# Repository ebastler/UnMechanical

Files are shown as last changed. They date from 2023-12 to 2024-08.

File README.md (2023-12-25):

# UnMechanical
 Unmechanical is an attempt to create a capacitive touch keyboard, replacing switches with touchpads.

 The operating principle is pretty much unchanged from the EC boards by [cipulot](https://github.com/Cipulot). Basically, the columns are strobed by the MCU, and the capacitive touchpad forms a capacitive voltage divider together with a 220pF resistor on the PCB. The voltage over the capacitor is measured to determine the capacity of the touchpad, which strongly changes if the pad is touched.

 In order to be able to scan multiple rows, the board uses an analog mux chip that switches from row to row. The input signal is amplified by an OPAMP, since QMK does not offer support for the STM32G431 built-in OPAMPs yet.

## Sweepish
So far, this repository contains a single board, "Sweepish", which consists of a Sweep 3x5 alpha cluster, and a modified 3 key thumb cluster. 

### Features:
* 36 capacitive touch-keys (Layout similar to Sweep)
* Magnetic split connect, allowing for unibody-use
* USB-C PD peripheral of the STM32G431 chip connected to USB-C port
* Circuitry and hole in PCB to mount a Switch Joycon haptic actuator and use it for typing feedback

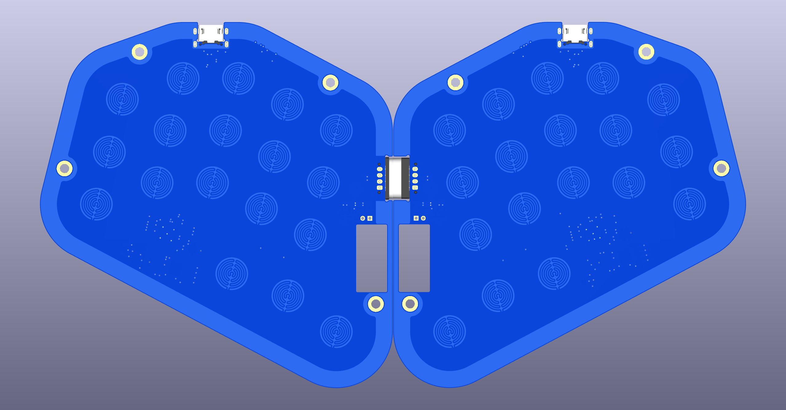
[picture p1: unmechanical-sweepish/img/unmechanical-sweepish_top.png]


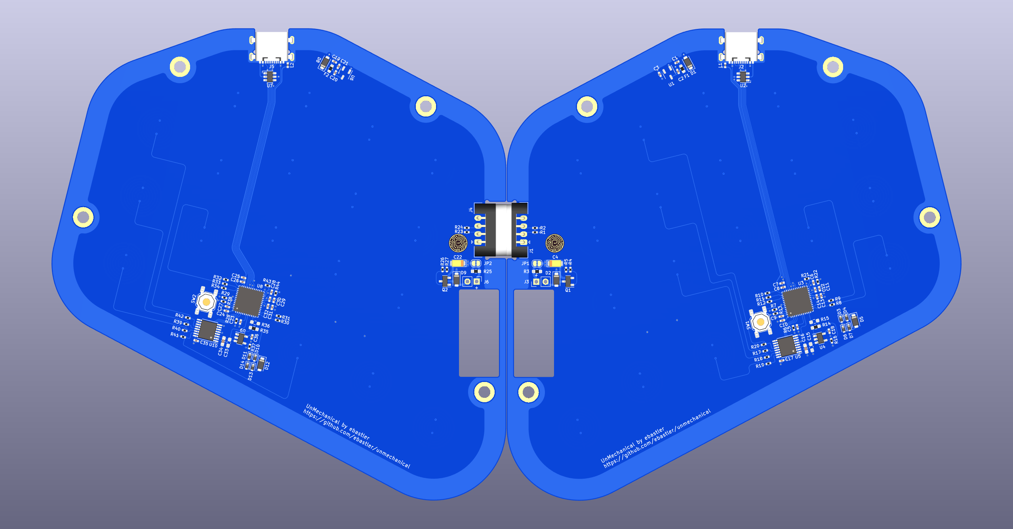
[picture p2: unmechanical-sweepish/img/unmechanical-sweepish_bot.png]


The board is designed to be used as a unibody, held together by HytePro M411P magnetic pogo connectors, but can also be made into a "proper" split board by using a magnetic cable assembly instead.

Firmware support, as well as some optimizations to make the board nicer to use, are still being worked on (so far it can only work as a single half, split EC keyscan does not work yet). The repo is only published as a proof-of-concept - more or less what the entire board design was for, in the first place. 

This keyboard also uses the USB-C PD peripheral of the STM32G431 since I wanted to make a test-board to experiment using it.

### Pictures
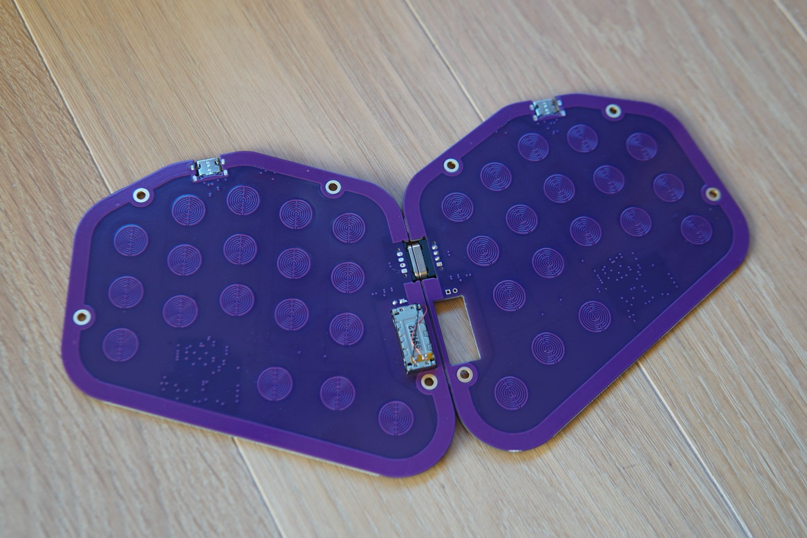
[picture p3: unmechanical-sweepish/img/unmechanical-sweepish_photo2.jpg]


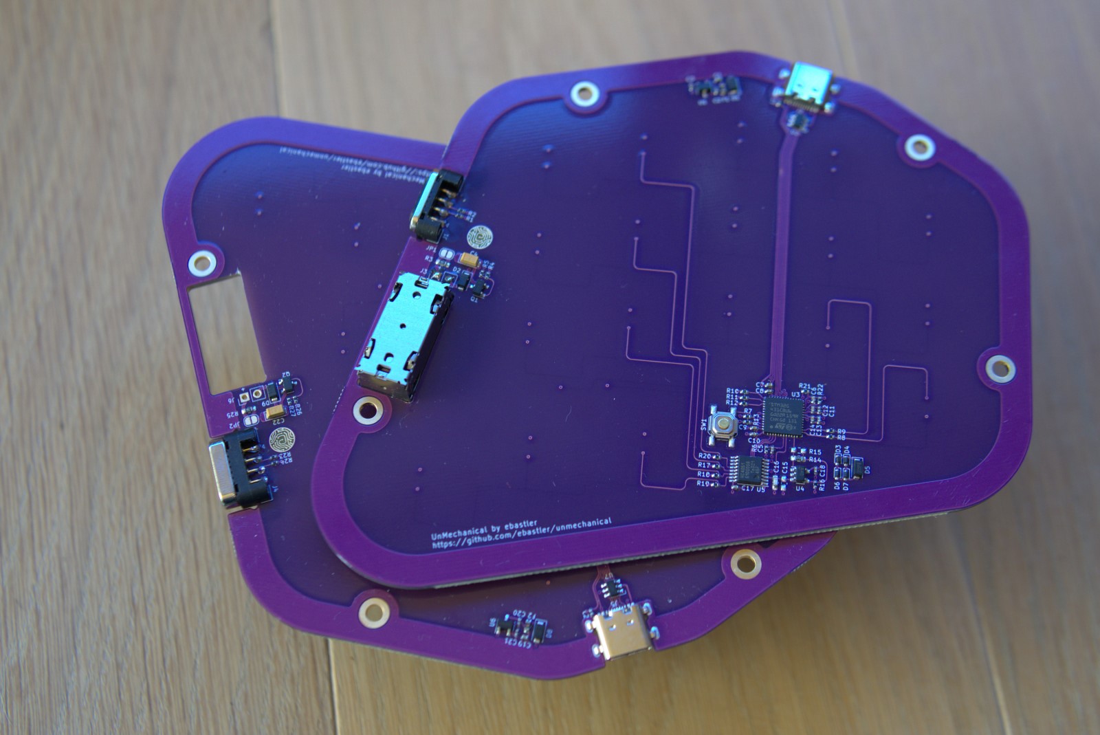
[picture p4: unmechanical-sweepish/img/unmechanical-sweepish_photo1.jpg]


A short video showing the board in action can be found on my youtube channel: https://youtu.be/7uHqJic0PQ8

## Thanks
* [cipulot](https://github.com/Cipulot) for his EC boards, EC QMK keyscan firmwares and help in developing this PCB
* [PCBWay](https://www.pcbway.com/) for the gorgeous sponsored PCBs - couldn't have done it without you!

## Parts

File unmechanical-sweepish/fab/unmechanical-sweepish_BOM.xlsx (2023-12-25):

Item | Reference(s) | Qty | Manufacturer | Manufacturer Part # | Value | Description | Footprint | Type | Notes
1 | C1, C7, C19, C25 | 4 |  |  | 4u7 | 4.7 uF ceramic capacitor, X5R or X7R, 10V, ± 20% or lower | C_0402 | SMD | Manufacturer does not matter
2 | C2, C3, C11, C13, C20, C21, C29, C31 | 8 |  |  | 1u | 1 uF ceramic capacitor, X5R or X7R, 10V, ± 20% or lower | C_0402 | SMD | Manufacturer does not matter
3 | C4, C22 | 2 |  |  | 10u | 10 uF tantalum capacitor, 16V or higher, ± 20% or lower | CP_3216-10_Kemet-A | SMD | Manufacturer does not matter
4 | C5, C6, C8, C9, C10, C14, C17, C18, C23, C24, C26, C27, C28, C32, C35, C36 | 16 |  |  | 100n | 100 nF ceramic capacitor, X5R or X7R, 10V or higher, ± 20% or lower | C_0402 | SMD | Manufacturer does not matter
5 | C12, C30 | 2 |  |  | 10n | 10 nF ceramic capacitor, X5R or X7R, 10V or higher, ± 20% or lower | C_0402 | SMD | Manufacturer does not matter
6 | C15, C33 | 2 |  | DNP | DNP |  | C_0603 | SMD | Do not populate
7 | C16, C34 | 2 |  |  | 220p | 220 pF ceramic capacitor, C0G, 10V or higher, ± 5% | C_0603 | SMD | Manufacturer does not matter
8 | D1, D2, D8, D9 | 4 |  | DS14W |  | 40 V 1 A Schottky diode | D_SOD-123F | SMD | Manufacturer does not matter
9 | D3, D4, D6, D7, D10, D11, D13, D14 | 8 |  | 1N4148WT |  |  | D_SOD-523 | SMD | Manufacturer does not matter
10 | D5, D12 | 2 |  | SMF3.3 |  | 3.3 V TVS diode | D_SOD-123F | SMD | Manufacturer does not matter
11 | F1, F2 | 2 | BHFUSE | BSMD0603-050-6V | 500 mA | 500 mA 6 V resettable polyfuse | Fuse_0603 | SMD | Manufacturer does not matter, other parts of similar specs can be used as replacement
12 | J1 | 1 | HytePro | HTP-CON-M411P-F |  | Spring-loaded magnetic connector | CON_HytePro_M411P_Plug | THT | J1 and J4 are sold as a pair: https://www.hyte.pro/product/m411p.html. Please make sure to not swap them – both should sit flush with PCB edge.
13 | J2, J5 | 2 | HRO Koreaparts | TYPE-C-31-M-14 |  | USB-C receptacle | USB_C_Receptacle_HRO_TYPE-C-31-M-14 | SMD/THT
14 | J4 | 1 | HytePro | HTP-CON-M411P-M |  | Spring-loaded magnetic connector | CON_HytePro_M411P_Receptacle | THT | J1 and J4 are sold as a pair: https://www.hyte.pro/product/m411p.html. Please make sure to not swap them – both should sit flush with PCB edge.
15 | L1, L2 | 2 | MuRata | BLM15PX121SN1D |  | Ferrite bead 2A 55 mOhm 120Ohm @ 100MHz | L_0402 | SMD
16 | Q1, Q2 | 2 | Alpha & Omega Semiconductor | AO3400A |  | 30 V 5.7 A n-ch MOSFET | SOT-23-3 | SMD
17 | R1, R2, R4, R8, R9, R10, R11, R12, R23, R24, R26, R30, R31, R32, R33, R34 | 16 |  |  | 100R | 100 Ohm 1/16W SMD resistor, ± 1% | R_0402 | SMD | Manufacturer does not matter
18 | R3, R25 | 2 |  |  | 4R7 | 4.7 Ohm 1/16W SMD resistor, ± 1% | R_0603 | SMD | Manufacturer does not matter
19 | R5, R6, R7, R13, R27, R28, R29, R38 | 8 |  |  | 10k | 10 kOhm 1/16W SMD resistor, ± 1% | R_0402 | SMD | Manufacturer does not matter
20 | R14, R35 | 2 |  |  | 100k | 100 kOhm 1/16W SMD resistor, ± 1% | R_0603 | SMD | Manufacturer does not matter
21 | R15, R36 | 2 |  | DNP | DNP |  | R_0603 | SMD | Do not populate
22 | R16, R37 | 2 |  |  | 1k | 1 kOhm 1/16W SMD resistor, ± 1% | R_0402 | SMD | Manufacturer does not matter
23 | R17, R18, R19, R20, R39, R40, R41, R42 | 8 |  |  | 100k | 100 kOhm 1/16W SMD resistor, ± 1% | R_0402 | SMD | Manufacturer does not matter
24 | R21, R22, R43, R44 | 4 |  |  | 4k7 | 4.7 kOhm 1/16W SMD resistor, ± 1% | R_0402 | SMD | Manufacturer does not matter
25 | SW1, SW2 | 2 | Alps Alpine | SKQGAKE010 |  | Alps SMD push button | SW_SPST_SKQG | SMD | All SKQGA*E010 models are acceptable as substitutes
26 | U1, U6 | 2 | Torex Semiconductor | XC6206P332MR |  | 3.3V low-dropout voltage regulator IC | SOT-23-3 | SMD
27 | U2, U7 | 2 |  | SRV05-4 |  | 4 channel ESD protection device | SOT-23-6 | SMD | Manufacturer does not matter
28 | U3, U8 | 2 | STMicroelectronics | STM32G431CBU6 |  | 32bit ARM Microcontroller | QFN-48-1EP_7x7mm_P0.5mm_EP5.6x5.6mm | SMD
29 | U4, U9 | 2 | Texas Instruments | OPA340NA |  | 1 channel rail-to-rail OPAMP | SOT-23-5 | SMD
30 | U5, U10 | 2 | Nexperia | 74HC4051PW,118 |  | 8bit analog Analog Switch/Multiplexer | TSSOP-16_4.4x5mm_P0.65mm | SMD

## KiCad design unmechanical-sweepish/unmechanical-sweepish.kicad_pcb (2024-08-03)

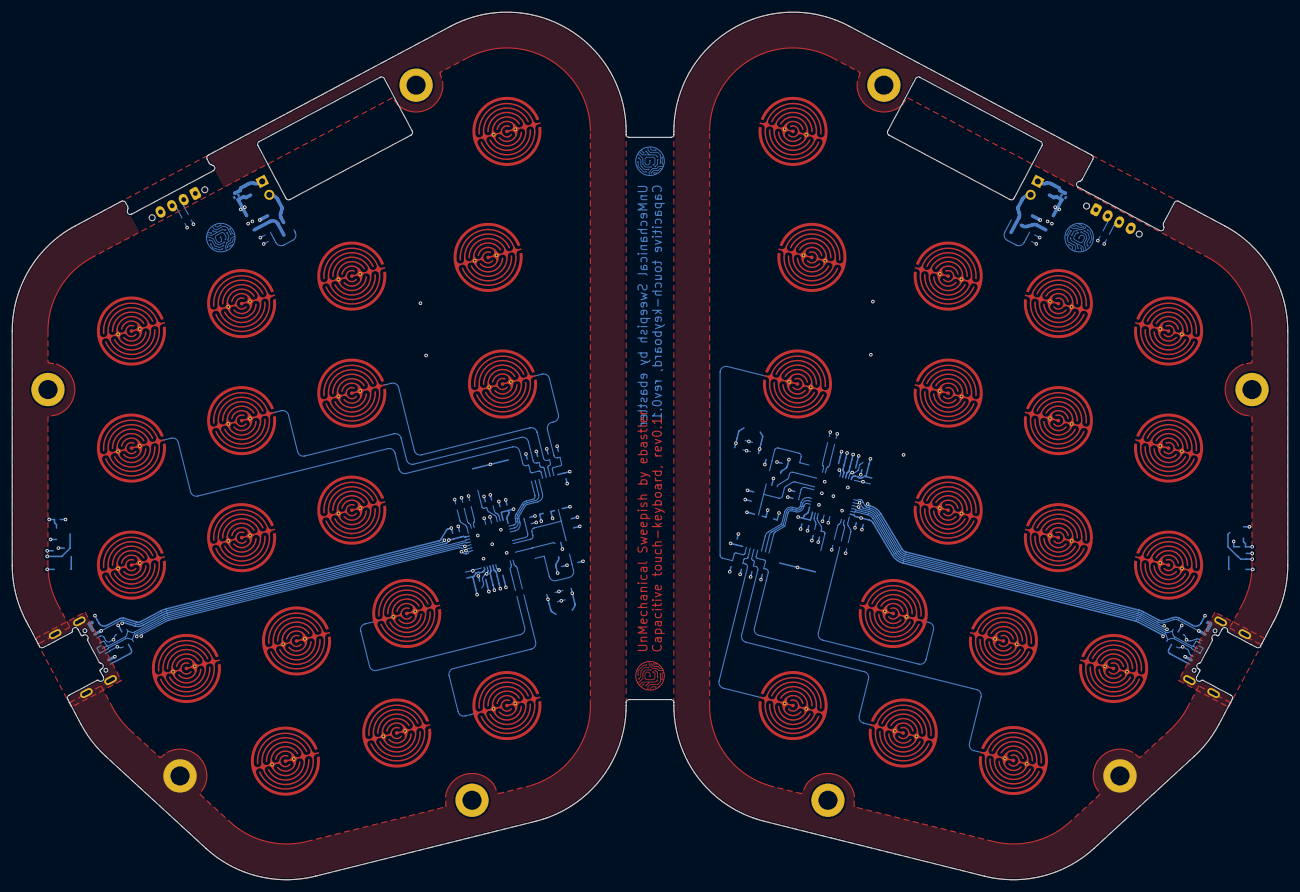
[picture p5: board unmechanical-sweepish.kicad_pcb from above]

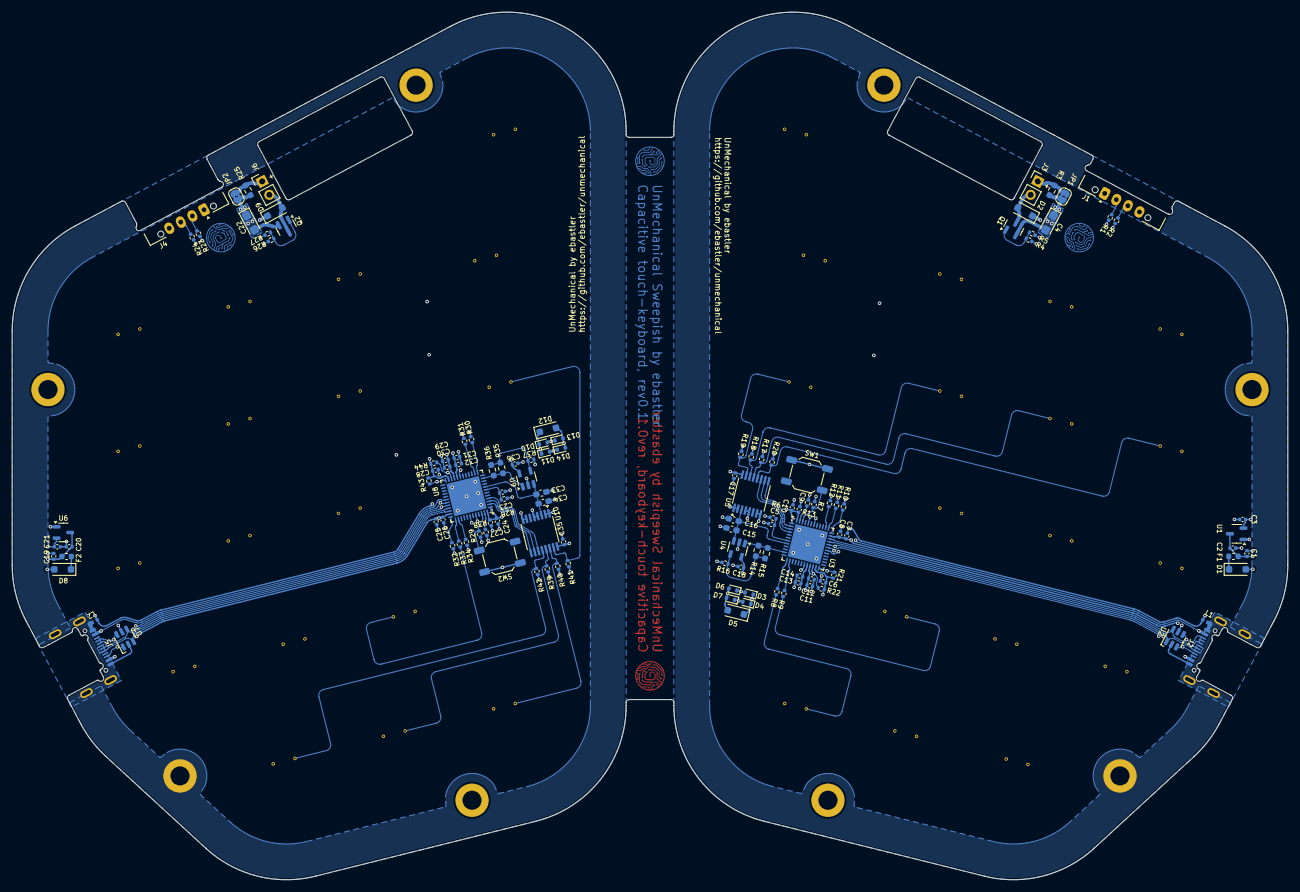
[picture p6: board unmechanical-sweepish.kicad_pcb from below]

Board: 4 copper layers, 214.0 x 145.5 mm, 164 parts (120 on the bottom side), 82 nets.

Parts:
C1, C7, C19, C25: 4u7; C_0402_1005Metric
C2, C3, C11, C13, C20, C21, C29, C31: 1u; C_0402_1005Metric
C4, C22: 10u; CP_EIA-3216-10_Kemet-I
C5, C6, C8, C9, C10, C14, C17, C18, C23, C24, C26, C27, C28, C32, C35, C36: 100n; C_0402_1005Metric
C12, C30: 10n; C_0402_1005Metric
C15, C33: DNP; C_0603_1608Metric_Pad1.08x0.95mm_HandSolder
C16, C34: 220p; C_0603_1608Metric_Pad1.08x0.95mm_HandSolder
D1, D2, D8, D9: D_Schottky; D_SOD-123F
D3, D4, D6, D7, D10, D11, D13, D14: 1N4148WT; D_SOD-523
D5, D12: SMF3.3; D_SOD-123F
EC1, EC2, EC3, EC4, EC5, EC6, EC7, EC8, EC9, EC10, EC11, EC12, EC13, EC14, EC15, EC16, EC17, EC18, EC19, EC20, EC21, EC22, EC23, EC24, EC25, EC26, EC27, EC28, EC29, EC30, EC31, EC32, EC33, EC34, EC35, EC36: EC; capsense_finger_1
F1, F2: Polyfuse; Fuse_0603_1608Metric
H1, H2, H3, H4, H5, H6, H7, H8: screw; MountingHole_3.2mm_M3_DIN965_Pad
J1: HytePro M; CON_HytePro_M411P_Plug_1x04-P2.20mm_Horizontal_FlushMount
J2, J5: USB_C_Receptacle_USB2.0; USB_C_Receptacle_HRO_TYPE-C-31-M-14
J3, J6: M; PinHeader_1x02_P2.54mm_Vertical
J4: HytePro F; CON_HytePro_M411P_Receptacle_1x04-P2.20mm_Horizontal_FlushM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
JP1, JP2: JP; SolderJumper-2_P1.3mm_Bridged2Bar_RoundedPad1.0x1.5mm
L1, L2: BLM15PX121SN1D; L_0402_1005Metric
Q1, Q2: AO3400A; SOT-23
R1, R2, R4, R8, R9, R10, R11, R12, R23, R24, R26, R30, R31, R32, R33, R34: 100R; R_0402_1005Metric
R3, R25: 4R7; R_0603_1608Metric_Pad0.98x0.95mm_HandSolder
R5, R6, R7, R13, R27, R28, R29, R38: 10k; R_0402_1005Metric
R14, R35: 100k; R_0603_1608Metric_Pad0.98x0.95mm_HandSolder
R15, R36: DNP; R_0603_1608Metric_Pad0.98x0.95mm_HandSolder
R16, R37: 1k; R_0402_1005Metric
R17, R18, R19, R20, R39, R40, R41, R42: 100k; R_0402_1005Metric
R21, R22, R43, R44: 4k7; R_0402_1005Metric
SW1, SW2: B/R; SW_SPST_SKQG_WithStem
U1, U6: XC6206PxxxMR; SOT-23-3
U2, U7: SRV05-4; SOT-23-6-routable
U3, U8: STM32G431CBUx; QFN-48-1EP_7x7mm_P0.5mm_EP5.6x5.6mm
U4, U9: OPA340NA; SOT-23-5
U5, U10: 74HC4051; TSSOP-16_4.4x5mm_P0.65mm

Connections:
+3.3V: C21.1, C24.1, C25.1, C26.1, C27.1, C28.1, C29.1, C30.1, C31.1, C32.1, C35.1, C36.1, D10.1 (K), D11.1 (K), D12.1 (K), R28.1, R43.1, R44.1, SW2.1, U6.2 (VO), U8.1 (VBAT), U8.20 (VREF+), U8.21 (VDDA), U8.23 (VDD), U8.35 (VDD), U8.48 (VDD), U9.5 (V+), U10.16 (VCC)
+3V3: C3.1, C6.1, C7.1, C8.1, C9.1, C10.1, C11.1, C12.1, C13.1, C14.1, C17.1, C18.1, D3.1 (K), D4.1 (K), D5.1 (K), R6.1, R13.2, R21.1, R22.1, SW1.1, U1.2 (VO), U3.1 (VBAT), U3.20 (VREF+), U3.21 (VDDA), U3.23 (VDD), U3.35 (VDD), U3.48 (VDD), U4.5 (V+), U5.16 (VCC)
+5V: C1.1, C2.1, C4.1, D2.1 (K), F1.2, J1.1, JP1.2 (B), R3.1, U1.3 (VI), U2.5 (VP)
+5VL: C19.1, C20.1, C22.1, D9.1 (K), F2.2, J4.1, JP2.2 (B), R25.1, U6.3 (VI), U7.5 (VP)
/unmechanical-sweepish-l/ADC: R14.2, R15.2, U3.11 (PA3), U4.1
/unmechanical-sweepish-l/BOOT0: R7.1, SW1.2, U3.46 (PB8)
/unmechanical-sweepish-l/CC1: J2.A5 (CC1), U2.3 (IO2), U3.31 (PA9), U3.44 (PB6)
/unmechanical-sweepish-l/CC2: J2.B5 (CC2), U2.4 (IO3), U3.32 (PA10), U3.42 (PB4)
/unmechanical-sweepish-l/USART3_RX: D3.2 (A), D6.1 (K), R2.1, R21.2, U3.24 (PB11)
/unmechanical-sweepish-l/USART3_TX: D4.2 (A), D7.1 (K), R1.1, R22.2, U3.22 (PB10)
/unmechanical-sweepish-l/USBGND: H1.1, J2.A1 (GND), J2.A12 (GND), J2.B1 (GND), J2.B12 (GND), J2.S1 (SHIELD), L1.1, U2.2 (VN)
/unmechanical-sweepish-l/USB_D+: J2.A6 (D+), J2.B6 (D+), U2.6 (IO4), U3.34 (PA12)
/unmechanical-sweepish-l/USB_D-: J2.A7 (D-), J2.B7 (D-), U2.1 (IO1), U3.33 (PA11)
/unmechanical-sweepish-l/VBUS: D1.2 (A), J2.A4 (VBUS), J2.A9 (VBUS), J2.B4 (VBUS), J2.B9 (VBUS), U3.30 (PA8)
/unmechanical-sweepish-l/amux_sel_0: U3.4 (PC15), U5.11 (S0)
/unmechanical-sweepish-l/amux_sel_1: U3.3 (PC14), U5.10 (S1)
/unmechanical-sweepish-l/amux_sel_2: U3.2 (PC13), U5.9 (S2)
/unmechanical-sweepish-l/aplex_out: C15.1, C16.1, U3.8 (PA0), U4.3 (+), U5.3 (A)
/unmechanical-sweepish-l/c0: EC1.2 (B), EC6.2 (B), EC11.2 (B), R8.2
/unmechanical-sweepish-l/c1: EC2.2 (B), EC7.2 (B), EC12.2 (B), R9.2
/unmechanical-sweepish-l/c2: EC3.2 (B), EC8.2 (B), EC13.2 (B), EC16.2 (B), R12.2
/unmechanical-sweepish-l/c3: EC4.2 (B), EC9.2 (B), EC14.2 (B), EC17.2 (B), R11.2
/unmechanical-sweepish-l/c4: EC5.2 (B), EC10.2 (B), EC15.2 (B), EC18.2 (B), R10.2
/unmechanical-sweepish-l/handsense: R13.1, U3.47 (PB9)
/unmechanical-sweepish-l/hapt: R4.1, U3.19 (PB2)
/unmechanical-sweepish-l/nRST: C5.2, R6.2, U3.7 (PG10)
/unmechanical-sweepish-l/r0: EC1.1 (A), EC2.1 (A), EC3.1 (A), EC4.1 (A), EC5.1 (A), R20.1, U5.12 (A3)
/unmechanical-sweepish-l/r1: EC6.1 (A), EC7.1 (A), EC8.1 (A), EC9.1 (A), EC10.1 (A), R17.1, U5.13 (A0)
/unmechanical-sweepish-l/r2: EC11.1 (A), EC12.1 (A), EC13.1 (A), EC14.1 (A), EC15.1 (A), R18.1, U5.14 (A1)
/unmechanical-sweepish-l/r3: EC16.1 (A), EC17.1 (A), EC18.1 (A), R19.1, U5.15 (A2)
/unmechanical-sweepish-r/ADC: R35.2, R36.2, U8.11 (PA3), U9.1
/unmechanical-sweepish-r/BOOT0: R29.1, SW2.2, U8.46 (PB8)
/unmechanical-sweepish-r/CC1: J5.A5 (CC1), U7.6 (IO4), U8.31 (PA9), U8.44 (PB6)
/unmechanical-sweepish-r/CC2: J5.B5 (CC2), U7.1 (IO1), U8.32 (PA10), U8.42 (PB4)
/unmechanical-sweepish-r/USART3_RX: D10.2 (A), D13.1 (K), R24.1, R43.2, U8.24 (PB11)
/unmechanical-sweepish-r/USART3_TX: D11.2 (A), D14.1 (K), R23.1, R44.2, U8.22 (PB10)
/unmechanical-sweepish-r/USBGND: H5.1, J5.A1 (GND), J5.A12 (GND), J5.B1 (GND), J5.B12 (GND), J5.S1 (SHIELD), L2.1, U7.2 (VN)
/unmechanical-sweepish-r/USB_D+: J5.A6 (D+), J5.B6 (D+), U7.3 (IO2), U8.34 (PA12)
/unmechanical-sweepish-r/USB_D-: J5.A7 (D-), J5.B7 (D-), U7.4 (IO3), U8.33 (PA11)
/unmechanical-sweepish-r/VBUS: D8.2 (A), J5.A4 (VBUS), J5.A9 (VBUS), J5.B4 (VBUS), J5.B9 (VBUS), U8.30 (PA8)
/unmechanical-sweepish-r/amux_sel_0: U8.4 (PC15), U10.11 (S0)
/unmechanical-sweepish-r/amux_sel_1: U8.3 (PC14), U10.10 (S1)
/unmechanical-sweepish-r/amux_sel_2: U8.2 (PC13), U10.9 (S2)
/unmechanical-sweepish-r/aplex_out: C33.1, C34.1, U8.8 (PA0), U9.3 (+), U10.3 (A)
/unmechanical-sweepish-r/c0: EC19.2 (B), EC24.2 (B), EC29.2 (B), EC34.2 (B), R30.2
/unmechanical-sweepish-r/c1: EC20.2 (B), EC25.2 (B), EC30.2 (B), EC35.2 (B), R31.2
/unmechanical-sweepish-r/c2: EC21.2 (B), EC26.2 (B), EC31.2 (B), EC36.2 (B), R34.2
/unmechanical-sweepish-r/c3: EC22.2 (B), EC27.2 (B), EC32.2 (B), R33.2
/unmechanical-sweepish-r/c4: EC23.2 (B), EC28.2 (B), EC33.2 (B), R32.2
/unmechanical-sweepish-r/handsense: R38.1, U8.47 (PB9)
/unmechanical-sweepish-r/hapt: R26.1, U8.19 (PB2)
/unmechanical-sweepish-r/nRST: C23.2, R28.2, U8.7 (PG10)
/unmechanical-sweepish-r/r0: EC19.1 (A), EC20.1 (A), EC21.1 (A), EC22.1 (A), EC23.1 (A), R42.1, U10.12 (A3)
/unmechanical-sweepish-r/r1: EC24.1 (A), EC25.1 (A), EC26.1 (A), EC27.1 (A), EC28.1 (A), R39.1, U10.13 (A0)
/unmechanical-sweepish-r/r2: EC29.1 (A), EC30.1 (A), EC31.1 (A), EC32.1 (A), EC33.1 (A), R40.1, U10.14 (A1)
/unmechanical-sweepish-r/r3: EC34.1 (A), EC35.1 (A), EC36.1 (A), R41.1, U10.15 (A2)
GND: C1.2, C2.2, C3.2, C4.2, C5.1, C6.2, C7.2, C8.2, C9.2, C10.2, C11.2, C12.2, C13.2, C14.2, C15.2, C16.2, C17.2, C18.2, D5.2 (A), D6.2 (A), D7.2 (A), J1.4, L1.2, Q1.2 (S), R5.2, R7.2, R16.2, R17.2, R18.2, R19.2, R20.2, U1.1 (GND), U3.49 (VSS), U4.2 (V-), U5.1 (A4), U5.2 (A6), U5.4 (A7), U5.5 (A5), U5.7 (VEE), U5.8 (GND)
GND1: C19.2, C20.2, C21.2, C22.2, C23.1, C24.2, C25.2, C26.2, C27.2, C28.2, C29.2, C30.2, C31.2, C32.2, C33.2, C34.2, C35.2, C36.2, D12.2 (A), D13.2 (A), D14.2 (A), J4.4, L2.2, Q2.2 (S), R27.2, R29.2, R37.2, R38.2, R39.2, R40.2, R41.2, R42.2, U6.1 (GND), U8.49 (VSS), U9.2 (V-), U10.1 (A4), U10.2 (A6), U10.4 (A7), U10.5 (A5), U10.7 (VEE), U10.8 (GND)
unnamed: D1.1 (K), F1.1
unnamed: D2.2 (A), J3.2, Q1.3 (D)
unnamed: D8.1 (K), F2.1
unnamed: D9.2 (A), J6.2, Q2.3 (D)
unnamed: J1.2, R1.2
unnamed: J1.3, R2.2
unnamed: J3.1, JP1.1 (A), R3.2
unnamed: J4.2, R23.2
unnamed: J4.3, R24.2
unnamed: J6.1, JP2.1 (A), R25.2
unnamed: Q1.1 (G), R4.2, R5.1
unnamed: Q2.1 (G), R26.2, R27.1
unnamed: R8.1, U3.13 (PA5)
unnamed: R9.1, U3.14 (PA6)
unnamed: R10.1, U3.36 (PA13)
unnamed: R11.1, U3.37 (PA14)
unnamed: R12.1, U3.38 (PA15)
unnamed: R14.1, R15.1, R16.1, U4.4 (-)
unnamed: R30.1, U8.13 (PA5)
unnamed: R31.1, U8.14 (PA6)
unnamed: R32.1, U8.36 (PA13)
unnamed: R33.1, U8.37 (PA14)
unnamed: R34.1, U8.38 (PA15)
unnamed: R35.1, R36.1, R37.1, U9.4 (-)

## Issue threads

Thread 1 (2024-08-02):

Request: add a "review" to the README

DeflateAwning, 2024-08-02:
This project seems super cool! Wish I saw it advertised in a blog/reddit post, instead of re-inventing the idea myself while daydreaming about a keyboard so thin I could store it between my laptop's existing keyboard and its screen.

Would love to see a 2-3 sentence-long review of the keyboard in the README so I know where the project is at! Should I buy it as-is for $50 to play with, or does it need a new rev before ordering? Are the thumb keys usable at all (my thumbs have a bone that prevents the tips from touching an iPad keyboard very well, for example)?

ebastler, 2024-08-03:
Hi! That's a good point, thanks. I must admit, I mainly pushed ahead with production of this board to be the first to publish such a keyboard design and due to technical interest, not so much due to actually wanting to use it (I am a terrible touch typist and struggle even with simple ergonomic boards like a Corne).

I made a proof of concept firmware back in the day that worked, but I failed in managing to get QMK split working with the capsense matrix scan code by @Cipulot . I know he expanded his code to support split operation right now, but afaik it has not been tested/adapted for this particular MCU yet. I mailed a pair of PCBs to him not too long ago, and hope he will be faster than me to get this working properly, at last.

I will give some more feedback once either Cip or I managed to create a working split-enabled firmware, as typing on half a keyboard is not particularly useful.

I also think some of the passives on the PCB need adjusting to get more sensitivity out of the capsense, but I have not dived into that yet. Basically something that can only be optimized through trial and error with a hot-air gun and patience.

In my testing, the board reliably recognized fingerprints, but it was not capable of doing so even through a very thin layer of plastic, for example 1mm thick 3D printed cover with grooves where the keys are to allow haptic homing. Swapping some passives in the feedback signal amplification part may, but is not guaranteed to improve this, and it may be that typing on the bare PCB remains the only option.

DeflateAwning, 2024-08-04:
I guess the big question: does it need a new revision before I order it to play with it (and maybe hopefully help contribute some firmware debugging), or is it pretty well ready-to-order as-is?

ebastler, 2024-08-05:
Cipulot said he'd like to experiment with the capacitors/resistors around the opamp which might improve reading strength by a lot - I'd wait for his results. I lacked a good sortiment of SMD parts myself so never got to do it.

I also noticed a bug in the USB-CC detection which explains some random behavior of not always being recognized immediately, I will fix that as well.

DeflateAwning, 2024-08-07:
@Cipulot, any updates or insight? Advice on next steps, or what you've tried so far?

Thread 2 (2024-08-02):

Request: Migrate to KiCAD v8

DeflateAwning, 2024-08-02:
Seems like the preview of the migration to KiCAD v8 missed some layers.

Would love to see it in the latest version to continue its development!

Specifically, it looks like the `User.Drawings` layer is offset. It's possible it was that way in a previous rev too though.

ebastler, 2024-08-03:
Thank you - the user.drawings layer was where I imported my CAD drawings, then apparently I did not rotate it along with the rest of the PCB when rearranging for panelization. I removed the contents of that layer altogether, as they are not necessary anymore and were just positioning aids to create the outline and switch positions.

Also, updated the footprints from library so 3D model paths are correct again (whyever they change between versions).

Closed 2024-08-03.

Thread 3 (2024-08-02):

Request: please tag releases with gerbers attached

DeflateAwning, 2024-08-02:
Please tag releases with gerber files (as zips) attached, as well as with schematics attached.

It makes it easier for noobs to get quotes, and to review the basic idea of the design, without having to muck around with KiCAD versions.

I'm really excited to explore this project more :)

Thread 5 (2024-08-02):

Bug: footprint libraries aren't in repo

DeflateAwning, 2024-08-02:
The footprint libraries aren't in this repo. They appear to be Global libraries, which reference a path on your computer.

It would be awesome if you could copy them into a project-specific library so they can be used within the repo. It's too bad this isn't the default.

ebastler, 2024-08-03:
Hi, the project uses my PCM lib [marbastlib](https://github.com/ebastler/marbastlib) - it references relative paths to the place where the KiCad PCM automatically installs libraries. If you want to use/access those footprints, you will have to install said library on your system.

Maintaining separate per-project libraries is way too much effort, and keeps me from improving and bugfixing footprints over time. Submodules make this a bit better, but are still a huge pain with relative paths to 3D models if everyone installs them to different paths. Using the KiCad package manager system for global libraries is the more effective approach.

Since KiCad caches all symbols/footprints in the project anyway, People can still use and edit the projects even without having the library installed anyway.

Closed 2024-08-03.

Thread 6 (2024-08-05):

USB-C CC detection not always working

ebastler, 2024-08-05:
With some cable/host combinations (and, oddly enough, some cable rotations) this PCB can act up and occasionally not be recognized, or recognized as a faulty USB device.

This most likely originates from the SRV05-4 being used for protection of the USB-C CC1/CC2 pins. USB-C hosts apply a voltage to the CC wire, and the device applies a 5.1kOhm resistor to it. The flowing current indicates the host's current capability to the client, and the client's existence to the host.

In the case of this board, some of this applied current can be leaked over the clamping diodes in the SRV05-4 onto +5V, and that causes trouble with a reliable detection.

Solution: Replace `SRV05-4` with a different type of ESD protection IC like `TPD4E02B04DQA`, which uses individual TVS diodes per data pin instead of clamping diodes + a single TVS diode.

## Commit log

2024-08-03 update to kicad 8 model paths
    [unmechanical-sweepish-l.kicad_sch, unmechanical-sweepish-r.kicad_sch, unmechanical-sweepish.kicad_pcb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]
2024-08-03 remove outdated graphics on user.drawings as reported in #2
    [unmechanical-sweepish.kicad_pcb]
